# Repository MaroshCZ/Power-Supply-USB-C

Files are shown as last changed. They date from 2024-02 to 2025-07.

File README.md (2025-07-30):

# Power Supply Sink Application

To learn more about text formatting see: [Writing-on-GitHub](https://docs.github.com/en/get-started/writing-on-github/getting-started-with-writing-and-formatting-on-github/basic-writing-and-formatting-syntax)

**demo-nucleo-v0**: Basic application for Nucleo-G0B1RE + SNK1M1 based on AN5418  
**demo-nucleo-v0.1**: USB PD app for Nucleo-G0B1RE + SNK1M1 with button-triggered APDO request  
**demo-cb-v0.1**: Demo for custom board derived from demo-nucleo-v0.1 (features APDO requests)

---

# [MiniPPS](https://yourprojectpage.dev/)  
*A USB-C Programmable Power Supply with Adjustable Voltage/Current and Digital Control*

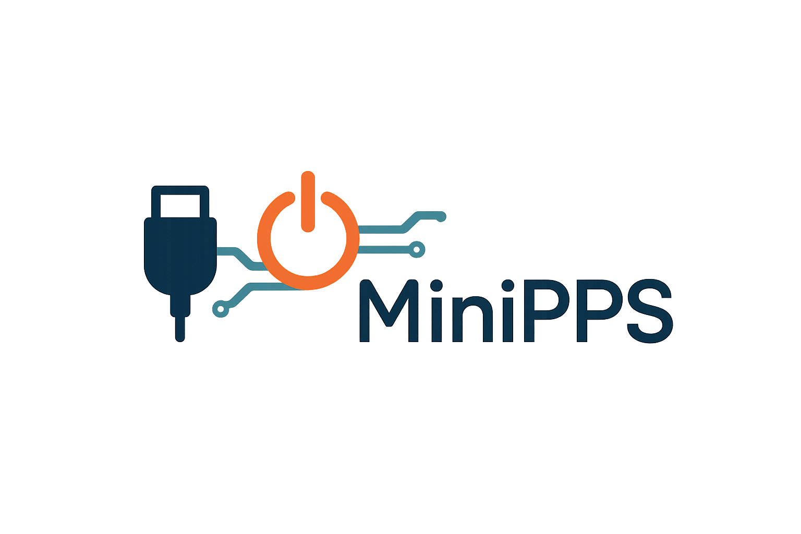
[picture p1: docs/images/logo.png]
SmartPPS banner


<div align="center">

<!--[![License](https://img.shields.io/badge/License-MIT-blue.svg)](https://opensource.org/licenses/MIT) --> 
  


</div>

---

## 📖 Table of Contents

- [Power Supply Sink Application](#power-supply-sink-application)
- [MiniPPS](#minipps)
  - [📖 Table of Contents](#-table-of-contents)
  - [🧠 About](#-about)
  - [⚙️ Features](#️-features)
    - [✅ Hardware](#-hardware)
    - [🎛️ User Interface](#️-user-interface)
    - [💻 Software](#-software)
  - [📐 Design Details](#-design-details)
    - [🔌 Schematic Overview](#-schematic-overview)
    - [🔒 Protections](#-protections)
  - [📊 Measured Performance](#-measured-performance)
  - [🛠️ Building the Project](#️-building-the-project)
  - [🚀 How to Use](#-how-to-use)
  - [🔮 Future Plans](#-future-plans)
  - [📄 License](#-license)
  - [🙏 Acknowledgments](#-acknowledgments)

---

## 🧠 About

MiniPPS is a compact, USB-C Programmable Power Supply designed to deliver **3.3V–21V**, up to **5A**, with **precision control** via buttons and an encoder. It supports USB PD 3.0 and PPS profiles and includes current sensing, SCPI command support, and optional remote control.

Ideal for embedded developers, hobbyists, and electronics students seeking a compact, user-friendly bench power supply.

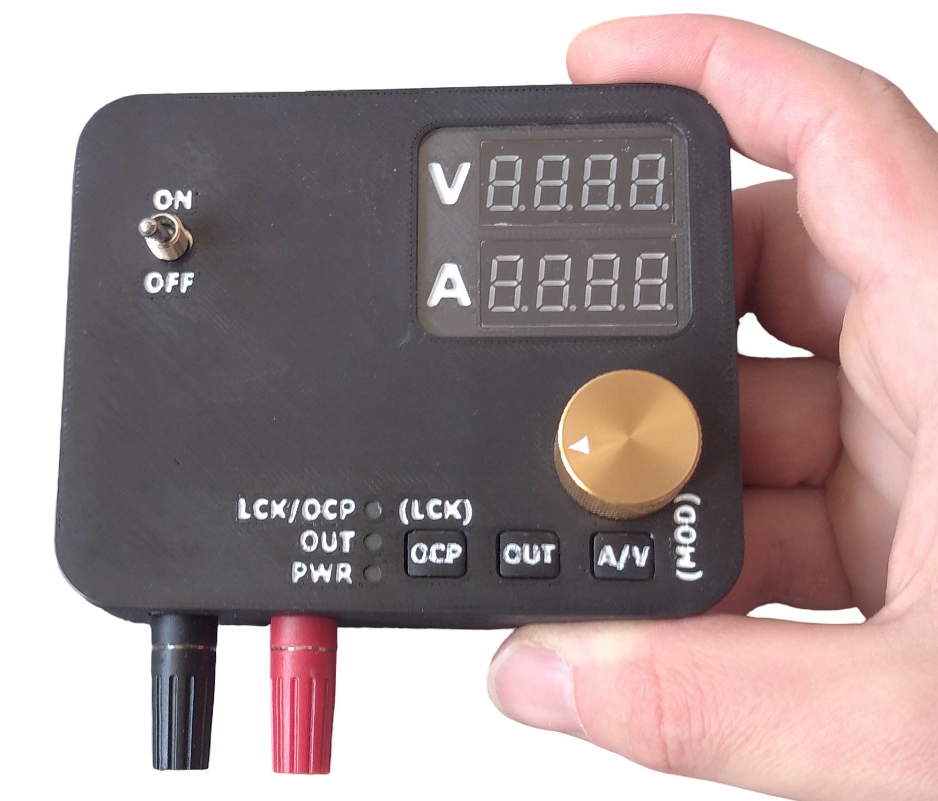
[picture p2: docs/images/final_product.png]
Device front view
<kbd></kbd>

---

## ⚙️ Features

### ✅ Hardware

- **USB-C PD Sink** supporting up to 100W (PD 3.0 + PPS)
- **TCPP01-M12** protection and **STM32G0B1RE** MCU
- **High-accuracy current sensing** (MCP6C02)
- Output switching (relay-based)
- **20mV / 1mA adjustment resolution**
- Dual 7-segment displays with MAX7219
- Optional UART interface for debugging with UCPMonitor
- Compact 4-layer PCB KiCad design

### 🎛️ User Interface

- Rotary encoder for setpoint control
- Three tactile buttons:
  - OUT on/off
  - OCP on/off + lock/unlock (long press)
  - Voltage/current + set mode (long press Fixed/PPS)
- Dual 7-segment LED display:
  - Real-time voltage/current
  - Set values display

### 💻 Software

- STM32 HAL + STM32CubeIDE (FreeRTOS optional)
- PID or step-based DAC/PWM voltage control
- Button debouncing, encoder 
- PD contract negotiation (APDO requests)
- SCPI protocol via USB for host communication with PC

---

## 📐 Design Details

### 🔌 Schematic Overview

<kbd>Block Diagram</kbd>

### 🔒 Protections

- Reverse voltage protection (Schottky diodes)
- Overcurrent protection (OCP) (MCP6C02 + AWDG/INA301 + alert) 
- Output controlled with relay
- OTP and OVP protections built into hardware (TCPP01-M12)

---

## 📊 Measured Performance

| Parameter | Value / Range |
|---|---|
| Output Voltage Range | 3.3V – 21V (depending on adapter) |
| Output Current Range | 0 – 5A |
| Max Output Power | 100W |
| Voltage Set Resolution | 20 mV |
| Current Set Resolution | 1 mA |
| Display Resolution (Voltage/Current)| 10 mV / 1 mA |
| Output Voltage Ripple (20 Hz–20 MHz)| 70–314 mVpp (depending on adapter) |
| Load Step Response Time | 0.6–21.4 ms (depending on adapter) |
| Rise/Fall Time (10–90%) | 32–428 μs |
| Voltage Accuracy (after calibration)| ±14 mV |
| Current Accuracy (after calibration)| ±4 mA |
| Protections | OVP (22V), OCP, OTP (145°C), ESD |
| Communication | USB Micro-B, custom SCPI protocol |
| Cooling | Passive (no fan) |
| Max Case Temperature @ Full Load | ~80°C (relay-based build) |
| Dimensions | 106 x 86 x 26 mm |
| Weight | 162 g |

---

## 🛠️ Building the Project

1. Download PCB Gerbers from `/hardware`
2. Order from a fab (e.g. [PCBWay](https://www.pcbway.com))
3. Assemble and solder components as per BOM
4. Flash firmware via ST-Link or Nucleo-G0B1RE
5. Connect USB-C PD source (charger or trigger)
6. Connect load and test via 4 mm banana terminals

See [Wiki – Assembly Guide](https://github.com/youruser/SmartPPS/wiki/Assembly-Guide) for details.

---

## 🚀 How to Use

1. Power the device using a USB-C PD charger or powerbank
2. Push encoder and select desired voltage or current
3. Press A/V to switch between settings
4. Press `Output ON/OFF` to enable the output
5. Monitor live output on the 7-segment display
6. Use `Lock` button to freeze or protect settings
7. Long press A/V button to switch between Fixed/PPS mode
8. Optionaly connect USB Micro-B to PC, open COM port and control via commands

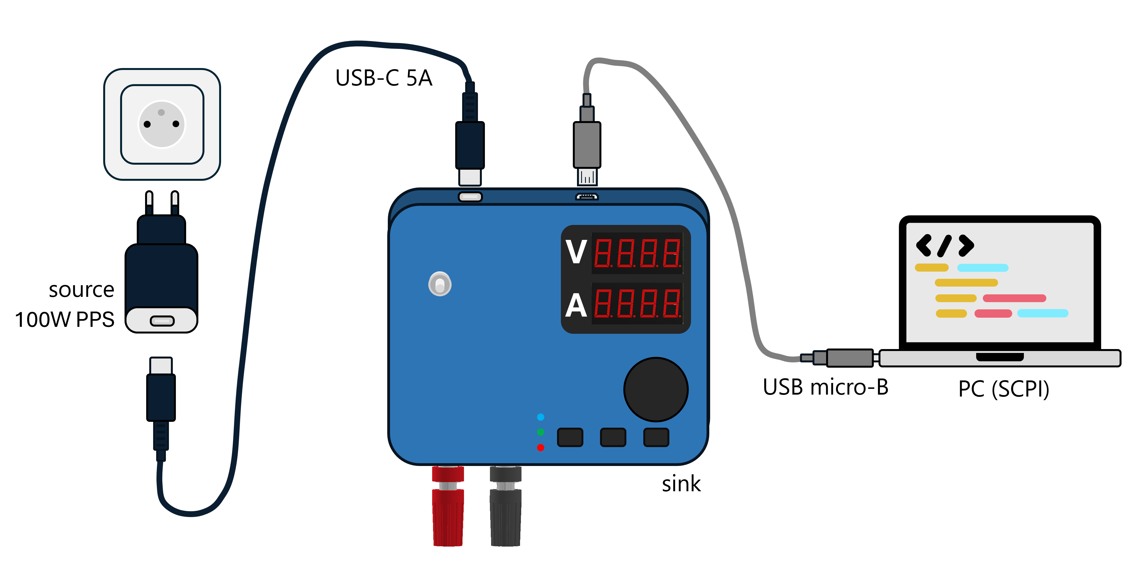
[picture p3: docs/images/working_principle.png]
Working principle
<kbd></kbd>

---

## 🔮 Future Plans

- USB PD 3.2 support (up to 48V / 5A)
- SCPI improvements and remote GUI (Qt/Python)
- Active cooling option
- Auto-ranging voltage dividers for better ADC precision
- Setting retention via emulated EEPROM

Track progress here: [GitHub Projects](https://github.com/users/youruser/projects/1)

---

## 📄 License

<!-- MIT License. See [LICENSE](LICENSE) for full details. -->

---

## 🙏 Acknowledgments

- Thanks to [STMicroelectronics](https://www.st.com/) for their excellent documentation and hardware samples
- Inspired by Tenma and RD Tech programmable PSUs
- Uses [MAX7219](https://datasheets.maximintegrated.com/en/ds/MAX7219-MAX7221.pdf), STM32G0, and KiCad
- Developed for engineers, students, and tinkerers 🚀
<!-- TODO: Developed as master thesis with collaboration and guidance from bender robotics -->

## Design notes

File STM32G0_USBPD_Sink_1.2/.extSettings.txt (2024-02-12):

[ProjectFiles]
HeaderPath=
[Others]
Define=
HALModule=
[Groups]
USBPD=USBPD\usbpd_user_services.c; USBPD\usbpd_user_services.h
Doc = C:\ST\STM32_CubeIDE\workspace1.14\UCPD\STM32G0_USBPD_Sink_1.2\Docs

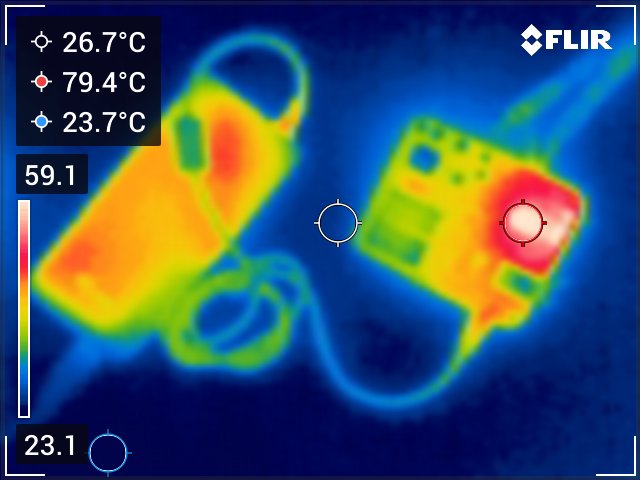
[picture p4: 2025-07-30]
docs/images/load_5A_adapter.jpg

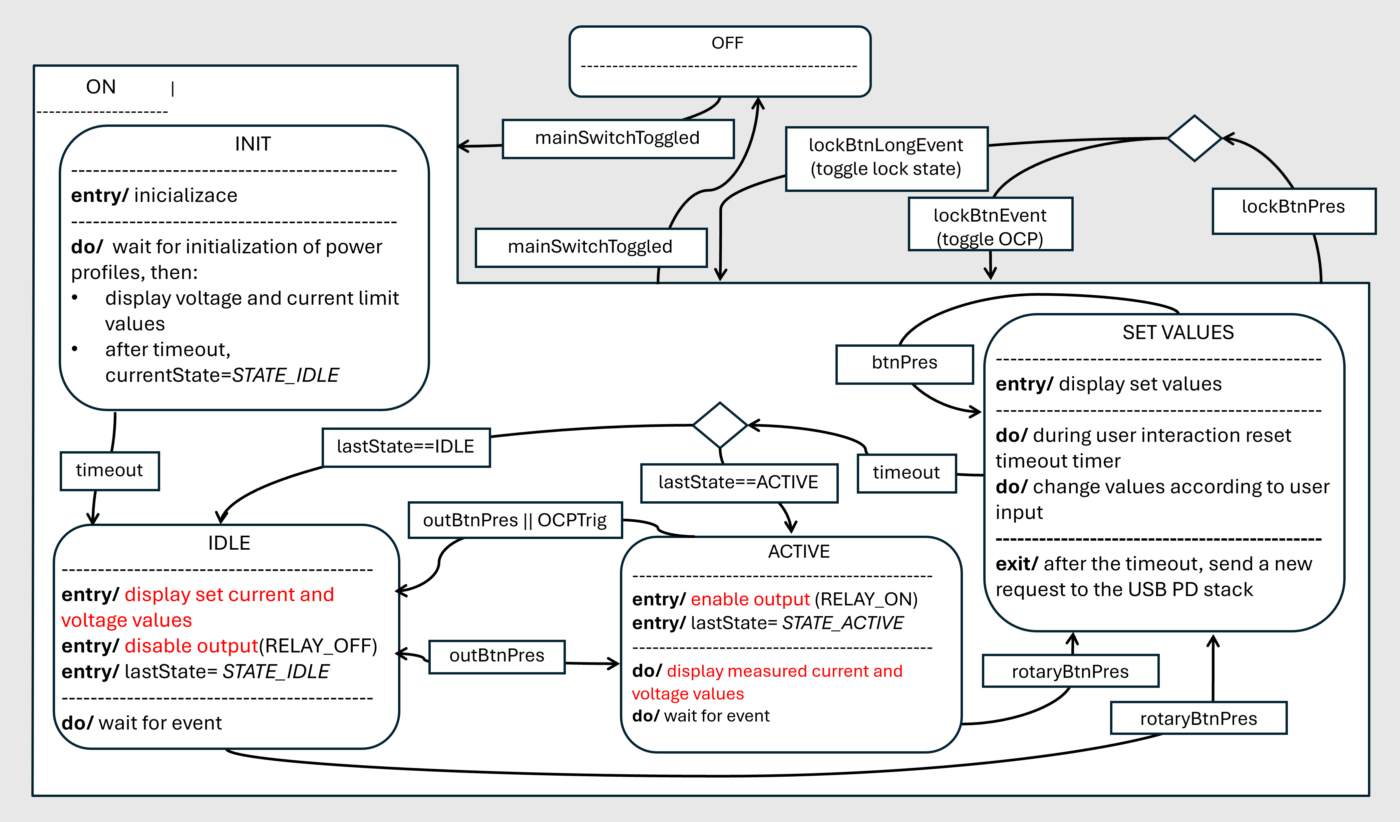
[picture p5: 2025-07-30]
docs/images/state_diagram.png

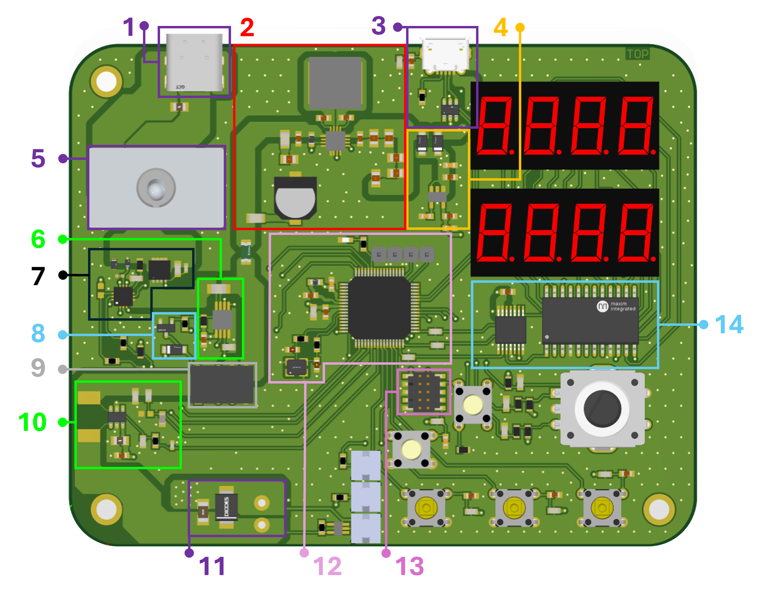
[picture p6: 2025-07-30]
docs/images/pcb_sections.png

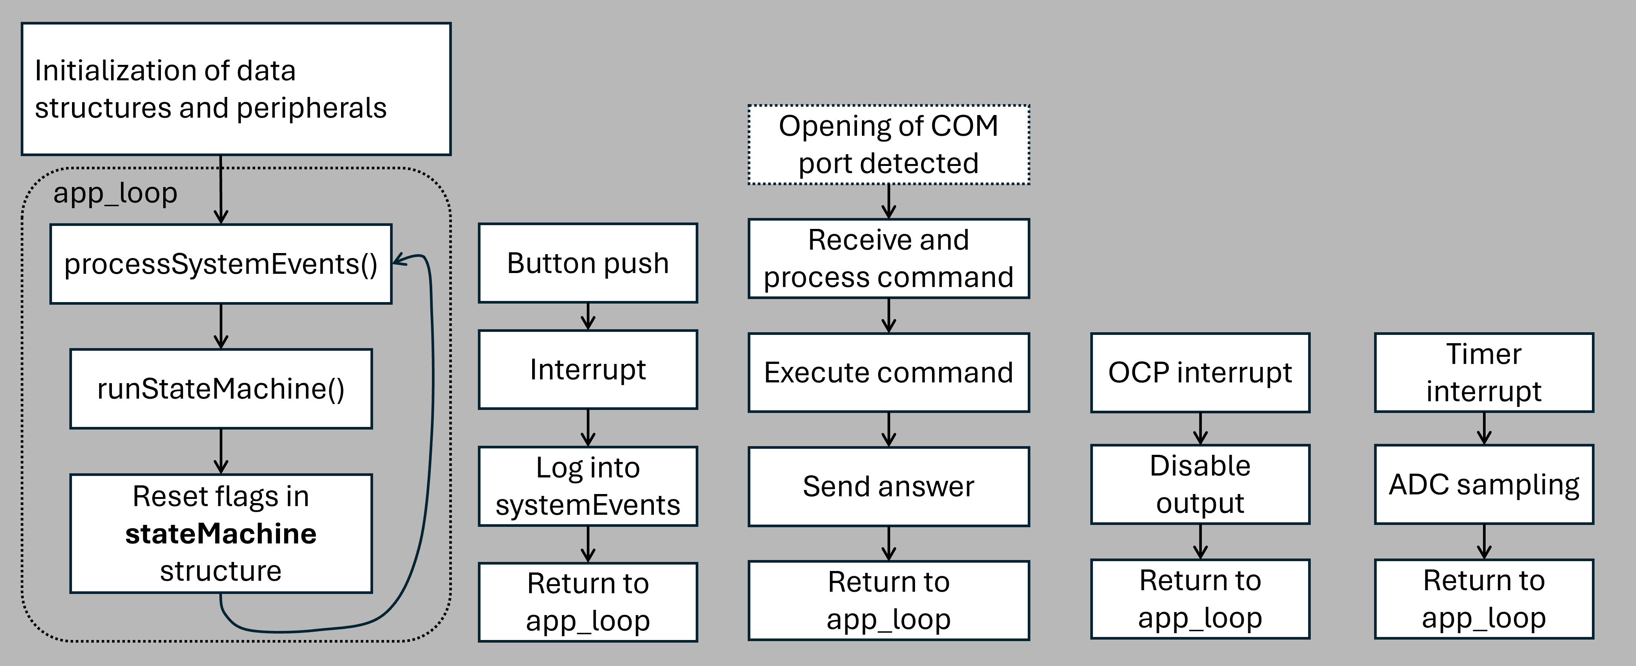
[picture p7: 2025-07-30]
docs/images/flow_diagram.png

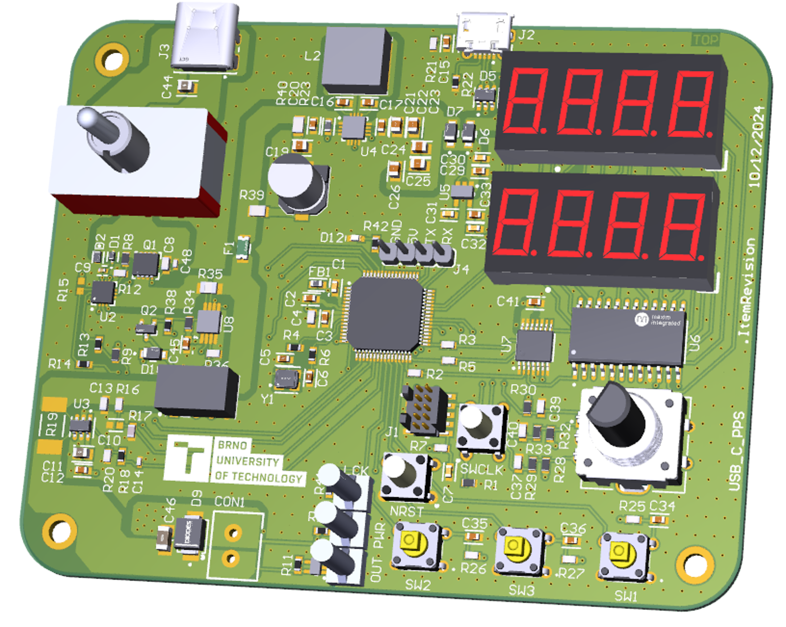
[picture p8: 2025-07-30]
docs/images/pps_dps_3d.png

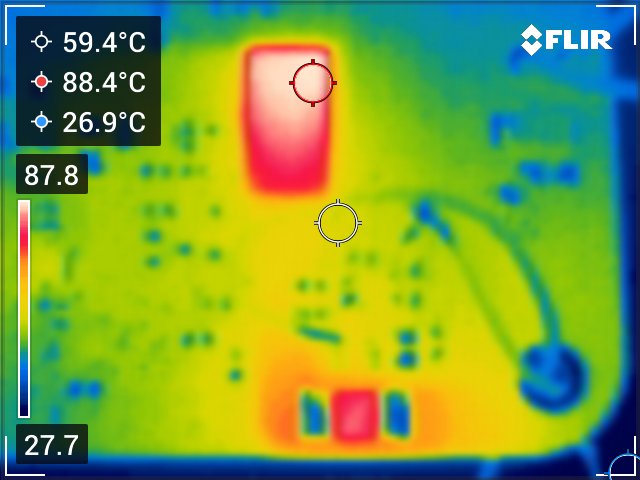
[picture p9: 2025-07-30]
docs/images/load_5A_detail.jpg

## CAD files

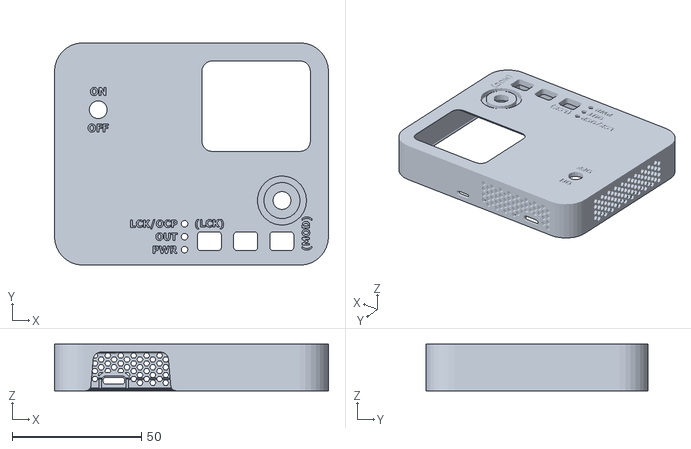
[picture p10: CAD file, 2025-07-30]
hardware/cad/Exports/top_enclosure.stl
106.0 x 86.0 x 18.0

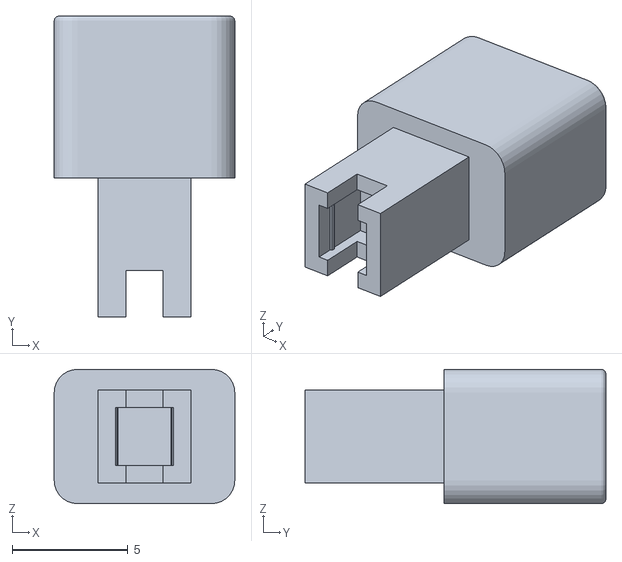
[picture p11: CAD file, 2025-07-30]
hardware/cad/Exports/button_cap.stl
7.80 x 13.0 x 5.80

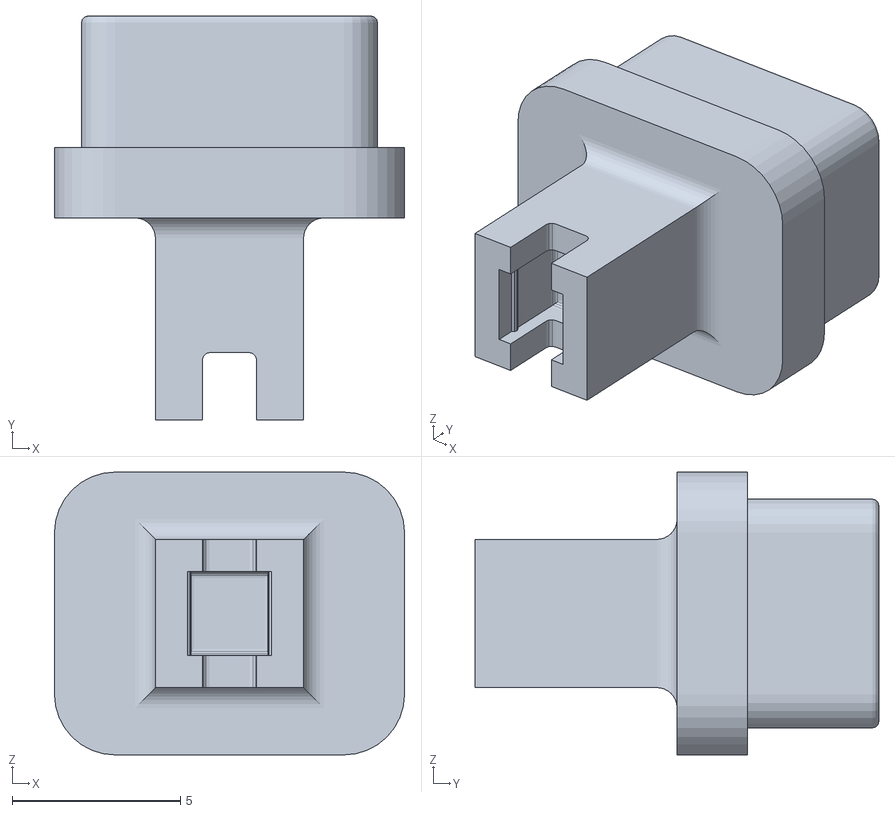
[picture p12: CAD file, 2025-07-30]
hardware/cad/Exports/button_cap_A_V.stl
10.4 x 12.0 x 8.40

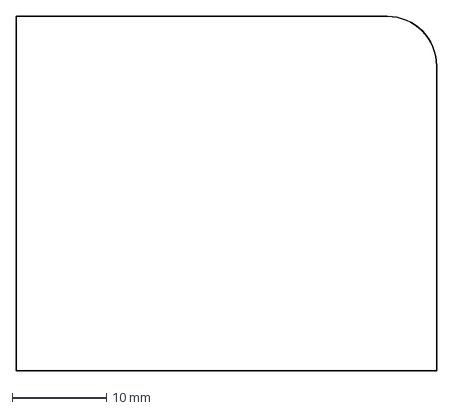
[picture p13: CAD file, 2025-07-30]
hardware/cad/Exports/plexiglass.dxf
44.5 x 37.5 mm

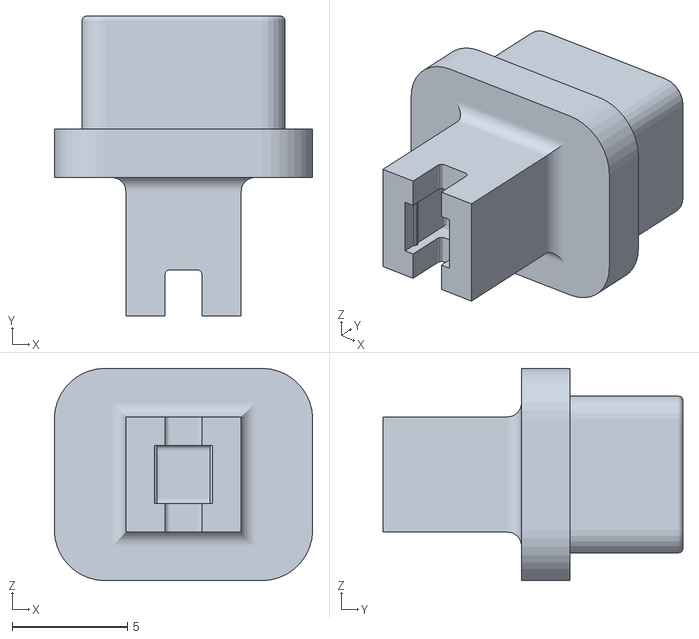
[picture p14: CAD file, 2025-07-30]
hardware/cad/Exports/button cap_v_0.4.stl
11.2 x 13.0 x 9.20

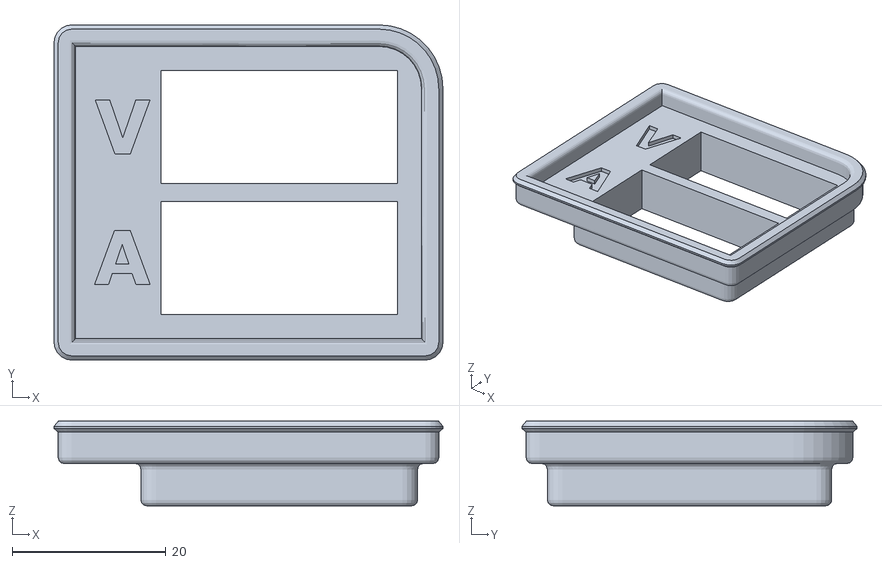
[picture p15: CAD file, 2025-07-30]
hardware/cad/Exports/display_cover_4mm.stl
50.6 x 43.6 x 11.0

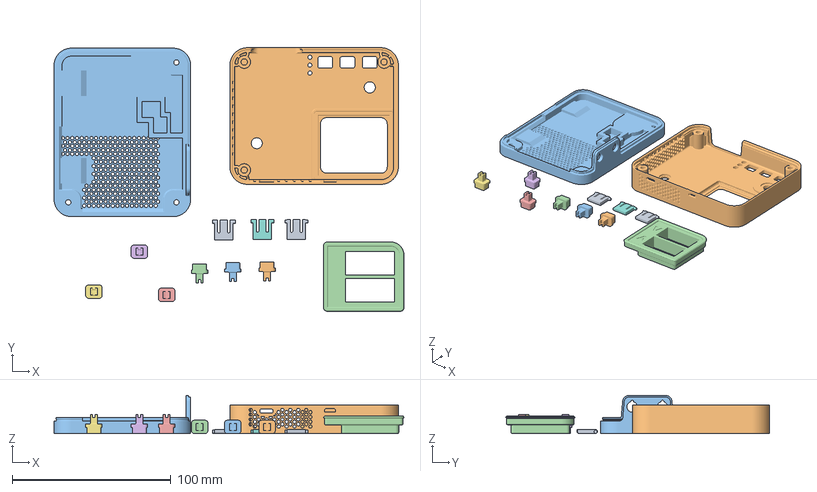
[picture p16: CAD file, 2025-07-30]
hardware/cad/Exports/bottom_enclosure_v_0.5.3mf
220.2 x 165.9 x 24.0 mm
tilt_leg_v_0.5.stl x 3
button_cap_A_V_v_0.5.stl x 2
button_cap_OUT_v_0.5.stl x 2
button_cap_OCP_v_0.5.stl x 2
top_enclosure
bottom_enclosure
display_cover_2

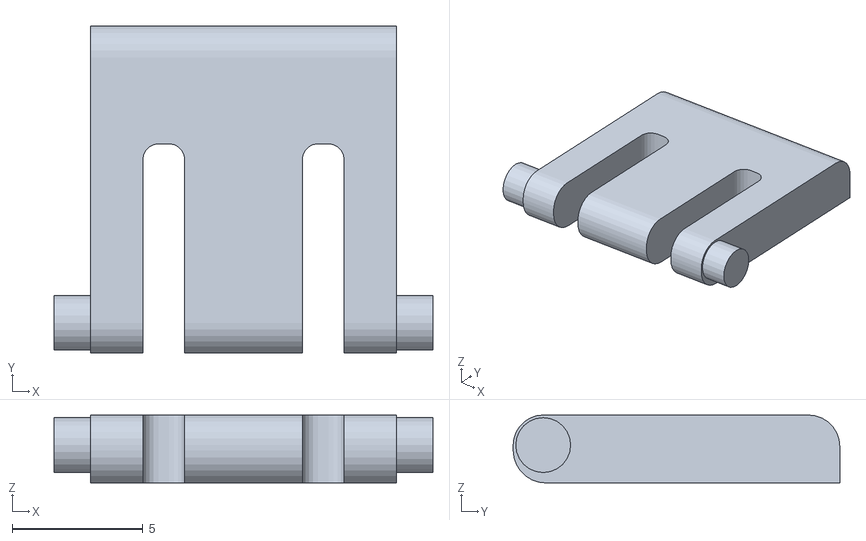
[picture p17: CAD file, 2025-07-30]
hardware/cad/Exports/tilt_leg.stl
14.5 x 12.5 x 2.60

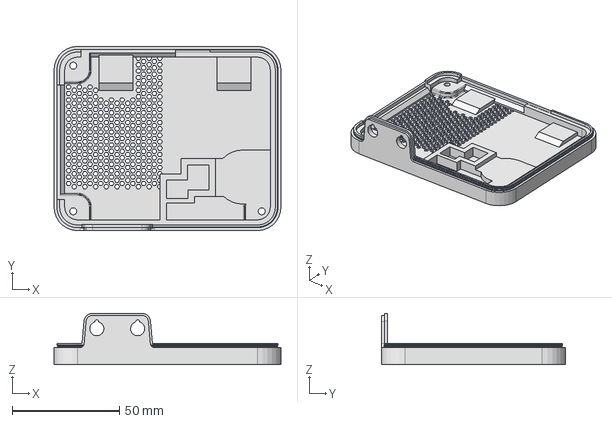
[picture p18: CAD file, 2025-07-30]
hardware/cad/Exports/bottom_enclosure.stp
106.0 x 86.0 x 24.0 mm

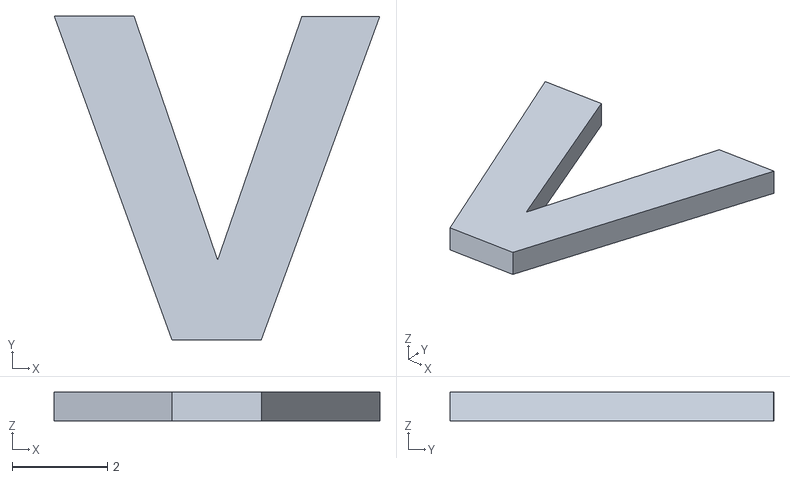
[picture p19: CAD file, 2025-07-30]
hardware/cad/Exports/V_letter.stl
6.84 x 6.81 x 0.6

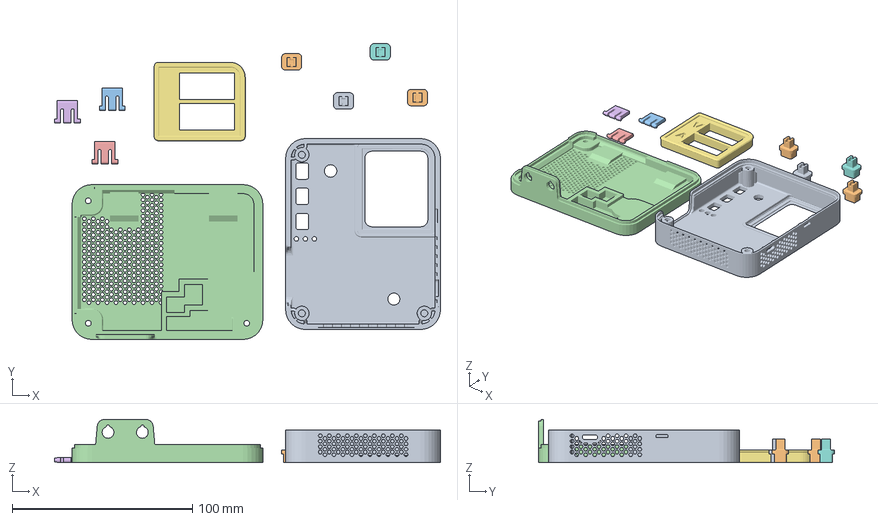
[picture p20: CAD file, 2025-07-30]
hardware/cad/Exports/print_prusa.3mf
214.3 x 164.3 x 24.0 mm
top_enclosure_v_0.4.stl
button cap_v_0.4.stl x 4
tilt_leg_v_0.4.stl x 3
bottom_enclosure_v_0.4.stl
display_cover_v_0.4.stl

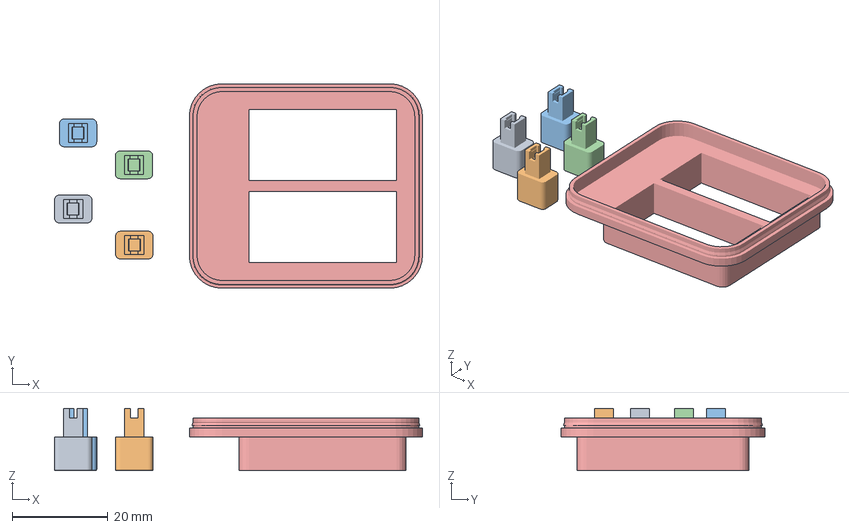
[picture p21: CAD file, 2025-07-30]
hardware/cad/Exports/display_cover_btns.3mf
76.7 x 42.6 x 13.0 mm
button_cap.stl x 4
display_cover.stl

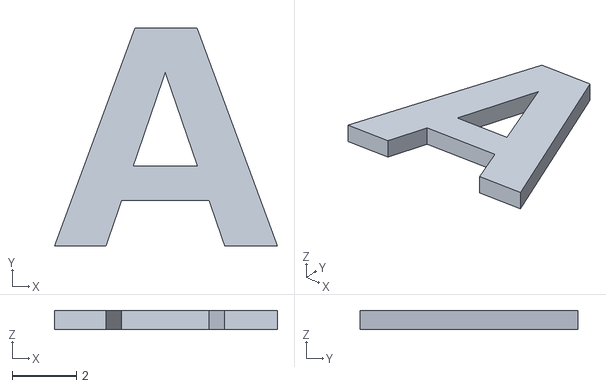
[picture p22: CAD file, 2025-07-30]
hardware/cad/Exports/A_letter.stl
6.96 x 6.80 x 0.6

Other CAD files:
hardware/cad/Exports/button_cap_OUT.stl
hardware/cad/Exports/display_cover_2mm.stp
hardware/cad/Exports/button_cap_OCP.stl
hardware/cad/A_letter.ipt
hardware/cad/ConvertedComponents/15EDGVC-3.5-02P-14_CMP-007-000009-5.ipt
hardware/cad/ConvertedComponents/1M41T1B5M1QE_1M41T1B5M1QE-1.ipt
hardware/cad/ConvertedComponents/3461AS_3461AS-1.ipt
hardware/cad/ConvertedComponents/B3F-1052_B3F-1052-1.ipt
hardware/cad/ConvertedComponents/B3F-1075_CMP-003-000047-3.ipt
hardware/cad/ConvertedComponents/C0603-IPC_B_CMP-001-00017-6.ipt
hardware/cad/ConvertedComponents/C0603-IPC_B_CMP-001-00021-6.ipt
hardware/cad/ConvertedComponents/C0603-IPC_B_CMP-001-00024-6.ipt
hardware/cad/ConvertedComponents/C0603-IPC_B_CMP-002-000092-6.ipt
hardware/cad/ConvertedComponents/CAPAE6866X80M_CMP-002-000028-3.ipt
hardware/cad/ConvertedComponents/CAPC1005X55X25NL05T10_CMP-2008-04045-1.ipt
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

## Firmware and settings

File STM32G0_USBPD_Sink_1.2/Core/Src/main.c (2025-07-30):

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
/* Includes ------------------------------------------------------------------*/
#include "main.h"
#include "cmsis_os.h"
#include "usbpd.h"
//#include "usb_device.h"

/* USER CODE BEGIN Includes */
#include <stdio.h>
#include <string.h>
#include <usbpd_trace.h>
#include <app.h>


/* USER CODE END Includes */

ADC_HandleTypeDef hadc1;
DMA_HandleTypeDef hdma_adc1;

DAC_HandleTypeDef hdac1;

SPI_HandleTypeDef hspi2;

TIM_HandleTypeDef htim3;
TIM_HandleTypeDef htim4;
TIM_HandleTypeDef htim15;

/* Definitions for defaultTask */
osThreadId_t defaultTaskHandle;
const osThreadAttr_t defaultTask_attributes = {
  .name = "defaultTask",
  .priority = (osPriority_t) osPriorityNormal,
  .stack_size = 128 * 4
};
void SystemClock_Config(void);
static void MX_GPIO_Init(void);
static void MX_DMA_Init(void);
static void MX_UCPD1_Init(void);
static void MX_ADC1_Init(void);
static void MX_LPUART1_UART_Init(void);
static void MX_TIM7_Init(void);
static void MX_SPI2_Init(void);
static void MX_TIM3_Init(void);
static void MX_DAC1_Init(void);
static void MX_TIM4_Init(void);
static void MX_TIM14_Init(void);
static void MX_TIM15_Init(void);
void StartDefaultTask(void *argument);

/**
  * @brief  The application entry point.
  * @retval int
  */
int main(void)
{
  /* MCU Configuration--------------------------------------------------------*/

  /* Reset of all peripherals, Initializes the Flash interface and the Systick. */
  HAL_Init();

  /* Configure the system clock */
  SystemClock_Config();

  /* Initialize all configured peripherals */
  MX_GPIO_Init();
  MX_DMA_Init();
  MX_UCPD1_Init();
  MX_ADC1_Init();
  MX_LPUART1_UART_Init();
  MX_TIM7_Init();
  MX_SPI2_Init();
  MX_TIM3_Init();
  MX_USB_Device_Init();
  MX_DAC1_Init();
  MX_TIM4_Init();
  MX_TIM14_Init();
  MX_TIM15_Init();
  /* USER CODE BEGIN 2 */
  app_init();
  /* USER CODE END 2 */

  /* Init scheduler */
  osKernelInitialize();
  /* USBPD initialisation ---------------------------------*/
  MX_USBPD_Init();

  /* USER CODE BEGIN RTOS_MUTEX */
  /* add mutexes, ... */
  /* USER CODE END RTOS_MUTEX */

  /* USER CODE BEGIN RTOS_SEMAPHORES */
  /* add semaphores, ... */
  /* USER CODE END RTOS_SEMAPHORES */

  /* USER CODE BEGIN RTOS_TIMERS */
  /* start timers, add new ones, ... */
  /* USER CODE END RTOS_TIMERS */

  /* USER CODE BEGIN RTOS_QUEUES */
  //app_freertos_create();
  /* USER CODE END RTOS_QUEUES */

  /* Create the thread(s) */
  /* creation of defaultTask */
  defaultTaskHandle = osThreadNew(StartDefaultTask, NULL, &defaultTask_attributes);

  /* USER CODE BEGIN RTOS_THREADS */
  /* add threads, ... */
  /* USER CODE END RTOS_THREADS */

  /* USER CODE BEGIN RTOS_EVENTS */
  /* add events, ... */
  /* USER CODE END RTOS_EVENTS */

  /* Start scheduler */
  osKernelStart();

  /* We should never get here as control is now taken by the scheduler */
  /* Infinite loop */
  /* USER CODE BEGIN WHILE */
  while (1)
  {
    /* USER CODE END WHILE */

    /* USER CODE BEGIN 3 */
  }
  /* USER CODE END 3 */
}

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
/* USER CODE BEGIN Header_StartDefaultTask */
/**
  * @brief  Function implementing the defaultTask thread.
  * @param  argument: Not used
  * @retval None
  */
/* USER CODE END Header_StartDefaultTask */
void StartDefaultTask(void *argument)
{
  /* USER CODE BEGIN 5 */
  /* Infinite loop */
  for(;;)
  {
    osDelay(1);
    app_loop();
  }
  /* USER CODE END 5 */
}

/**
  * @brief  Period elapsed callback in non blocking mode
  * @note   This function is called  when TIM6 interrupt took place, inside
  * HAL_TIM_IRQHandler(). It makes a direct call to HAL_IncTick() to increment
  * a global variable "uwTick" used as application time base.
  * @param  htim : TIM handle
  * @retval None
  */
void HAL_TIM_PeriodElapsedCallback(TIM_HandleTypeDef *htim)
{
  if (htim->Instance == TIM6) {
    HAL_IncTick();
  }
  /* USER CODE BEGIN Callback 1 */
  USBPD_DPM_TimerCounter(); //related to PD device manager
  GUI_TimerCounter(); //updating a graphical user interface (GUI) based on timer events.
  /* USER CODE END Callback 1 */
}

/**
  * @brief  This function is executed in case of error occurrence.
  * @retval None
  */
void Error_Handler(void)
{
  /* USER CODE BEGIN Error_Handler_Debug */
  /* User can add his own implementation to report the HAL error return state */
  __disable_irq();
  while (1)
  {
  }
  /* USER CODE END Error_Handler_Debug */
}

#ifdef  USE_FULL_ASSERT
/**
  * @brief  Reports the name of the source file and the source line number
  *         where the assert_param error has occurred.
  * @param  file: pointer to the source file name
  * @param  line: assert_param error line source number
  * @retval None
  */
void assert_failed(uint8_t *file, uint32_t line)
{
  /* USER CODE BEGIN 6 */
  /* User can add his own implementation to report the file name and line number,
     ex: printf("Wrong parameters value: file %s on line %d\r\n", file, line) */
  /* USER CODE END 6 */
}
#endif /* USE_FULL_ASSERT */

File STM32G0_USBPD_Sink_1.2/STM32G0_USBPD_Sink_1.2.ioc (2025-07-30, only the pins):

Mcu.UserName=STM32G0B1RETx
PA0.GPIO_Label=HighZ
PA0.Signal=GPIO_Input
PA1.GPIO_Label=FLT_IN_TCPP
PA1.Signal=GPIO_Input
PA13.Signal=SYS_SWDIO
PA14-BOOT0.Signal=SYS_SWCLK
PA2.Signal=LPUART1_TX
PA3.Signal=LPUART1_RX
PA4.GPIO_Label=OCP_DAC_LIMIT
PA4.Signal=COMP_DAC11_group
PA5.GPIO_Label=VSENSE
PA5.Signal=ADC1_IN5
PA6.GPIO_Label=OCP_ADC_I
PA6.Signal=ADC1_IN6
PA7.GPIO_Label=ISENSE
PA7.Signal=ADC1_IN7
PA8.Signal=UCPD1_CC1
PB0.GPIO_Label=DB_OUT
PB0.Signal=GPIO_Output
PB1.GPIO_Label=SW3_OFF_ON
PB1.Signal=GPXTI1
PB11.Signal=SPI2_MOSI
PB12.GPIO_Label=CS_MAX7219
PB12.Signal=GPIO_Output
PB13.Signal=SPI2_SCK
PB15.Signal=UCPD1_CC2
PB2.GPIO_Label=SW1_TOGGLE_I_V
PB2.Signal=GPXTI2
PB4.GPIO_Label=CC2_G4
PB4.Signal=GPIO_Input
PB5.GPIO_Label=LED_USER
PB5.Signal=GPIO_Output
PB6.GPIO_Label=OCP_ALERT
PB6.Signal=GPXTI6
PB7.GPIO_Label=OCP_ALERT2
PB7.Signal=GPXTI7
PB8.GPIO_Label=OCP_RESET
PB8.Signal=GPIO_Output
PC10.GPIO_Label=RELAY_ON_OFF
PC10.Signal=GPIO_Output
PC4.GPIO_Label=SW2_DEBUG_BTN
PC4.Signal=GPXTI4
PC5.GPIO_Label=LED_LOCK
PC5.Signal=GPIO_Output
PC6.GPIO_Label=ENC_TIM3_CH1
PC6.Signal=S_TIM3_CH1
PC7.GPIO_Label=ENC_TIM3_CH2
PC7.Signal=S_TIM3_CH2
PD8.GPIO_Label=ENC_TOGGLE_UNITS
PD8.Signal=GPXTI8

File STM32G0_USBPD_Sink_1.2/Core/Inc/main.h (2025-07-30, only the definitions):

#define VDDA_APPLI 3300
#define HighZ_Pin GPIO_PIN_0
#define HighZ_GPIO_Port GPIOA
#define FLT_IN_TCPP_Pin GPIO_PIN_1
#define FLT_IN_TCPP_GPIO_Port GPIOA
#define OCP_DAC_LIMIT_Pin GPIO_PIN_4
#define OCP_DAC_LIMIT_GPIO_Port GPIOA
#define VSENSE_Pin GPIO_PIN_5
#define VSENSE_GPIO_Port GPIOA
#define OCP_ADC_I_Pin GPIO_PIN_6
#define OCP_ADC_I_GPIO_Port GPIOA
#define ISENSE_Pin GPIO_PIN_7
#define ISENSE_GPIO_Port GPIOA
#define SW2_DEBUG_BTN_Pin GPIO_PIN_4
#define SW2_DEBUG_BTN_GPIO_Port GPIOC
#define SW2_DEBUG_BTN_EXTI_IRQn EXTI4_15_IRQn
#define LED_LOCK_Pin GPIO_PIN_5
#define LED_LOCK_GPIO_Port GPIOC
#define DB_OUT_Pin GPIO_PIN_0
#define DB_OUT_GPIO_Port GPIOB
#define SW3_OFF_ON_Pin GPIO_PIN_1
#define SW3_OFF_ON_GPIO_Port GPIOB
#define SW3_OFF_ON_EXTI_IRQn EXTI0_1_IRQn
#define SW1_TOGGLE_I_V_Pin GPIO_PIN_2
#define SW1_TOGGLE_I_V_GPIO_Port GPIOB
#define SW1_TOGGLE_I_V_EXTI_IRQn EXTI2_3_IRQn
#define CS_MAX7219_Pin GPIO_PIN_12
#define CS_MAX7219_GPIO_Port GPIOB
#define ENC_TIM3_CH1_Pin GPIO_PIN_6
#define ENC_TIM3_CH1_GPIO_Port GPIOC
#define ENC_TIM3_CH2_Pin GPIO_PIN_7
#define ENC_TIM3_CH2_GPIO_Port GPIOC
#define ENC_TOGGLE_UNITS_Pin GPIO_PIN_8
#define ENC_TOGGLE_UNITS_GPIO_Port GPIOD
#define ENC_TOGGLE_UNITS_EXTI_IRQn EXTI4_15_IRQn
#define CC2_G4_Pin GPIO_PIN_4
#define CC2_G4_GPIO_Port GPIOB
#define LED_USER_Pin GPIO_PIN_5
#define LED_USER_GPIO_Port GPIOB
#define OCP_ALERT_Pin GPIO_PIN_6
#define OCP_ALERT_GPIO_Port GPIOB
#define OCP_ALERT_EXTI_IRQn EXTI4_15_IRQn
#define OCP_ALERT2_Pin GPIO_PIN_7
#define OCP_ALERT2_GPIO_Port GPIOB
#define OCP_ALERT2_EXTI_IRQn EXTI4_15_IRQn
#define OCP_RESET_Pin GPIO_PIN_8
#define OCP_RESET_GPIO_Port GPIOB
#define RELAY_ON_OFF_Pin GPIO_PIN_10
#define RELAY_ON_OFF_GPIO_Port GPIOC

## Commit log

2024-02-06 Basic application of USB-C power sink. Includes also user debugg button.
    [Configuration_2024_01_24_MB1360-COM3_0.txt]
2024-02-17 Change to function HAL_TIM_PeriodElapsedCallback
    Added USBPD and GUI_TImerCOunter() so UCPD monitor GUI now shows measured voltage in chart.
2024-02-26 Implementation of Request Power profile in GUI
    Implementation of function RequestMessageRequest inside usbpd_dpm_user.c. For this purpose also funstions in usbpd_user_services.c (EvaluateMatchWithSRCPDO and BuildRDOfromSelectedPDO) were exported 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
    [Configuration_2024_02_20_Vention.txt]
2024-03-20 feat: Implement APDO power profile request with arbitrary voltage
    - previously only max voltage APDO request was possible
    - now user can request power profile with arbitrary APDO voltage in UCPD-Monitor
2024-03-21 chore: Change the folder structure
    - create new folders for docs and hardware
    - move UCPD config folder inside STM project folder
    [Configuration_2024_02_20_Vention.txt]
2024-03-26 feature: Add new project for UI testing
    - add new project for testing user interface
    - set TIM2 in encoder mode
    - add input filters to TIM2 channels
    - set encoder mode to TI1 and TI2 to detect both turning directions
    - enable auto-reload preload for TIM2
    - set SYS timebase source to TIM6
2024-03-26 feat: Add user application folder, header and source file
    [STM32G0_encoder Debug.cfg]
2024-03-26 feat: Add encoder reading
    - add encoderVal variable to store the encoder reading
    - get encoderVal reading from TIM2 counter register
2024-03-26 feat: Add encoder button press feature
    - create encoderPress variable
    - add logic for button press
    - clear EXTI interrupt flag at the end of button_isr function
    - link app_encoder.h and add button_isr to src/stm32g0xx_it.c
2024-03-26 feat: Add encoder button debouncing
    - set TIM7 debounce period to about 100ms
    - enable TIM7 IT update
    - mask interrupts on EXTI line 3 and count up to 100ms with TIM7 on each button_isr run
    - umask interrupts on EXTI line 3 and clear TIM7 update flag in timer interrupt routine
2024-04-07 fix: Change encoderBtn GPIO to falling edge detection with pull up
    [main.c]
2024-04-07 fix: Increase EncoderBtn debouncing to 150ms (TIM7)
    [main.c]
2024-04-11 feat: Add CS pin for segment display (PB0)
    - add CS pin for segment display
    - change the encoderPress logic to decrementing
2024-04-11 feat: Add voltage value based on encoder turning
    - detect the direction of encoder turning
    - define values to be added based on digit (1, 0.1,...)
    - if voltageTemp wihin limit save it to voltage variable
2024-04-11 feat: Add detection of number of integer digits and print value on display
    - add logic for detecting number of integer digits and save it to num_digits
2024-04-21 fix: Change float voltage to int
    - solve problem with float display
    - change adding variable val to integers (1,10,..)
    - change encoderPress range to 0-3
    - add for loop for printing starting zeroes
2024-04-21 feat: Add leading zero and decimal point to max7219_PrintItos
    - add third function argument for decimal point place
    - add num_digits which gets number of significant digits
    - add for loop for printing leading zeros
    - add decimal point printing using max7219_PrintDigit
2024-04-29 feat: Add TIM2 for rotary encoder
    - add TIM2 in encoder mode
    - set channel filters to 12
    - change SYS timer to TIM6 (SysTick not reccomended due to FreeRTOS)
    - enable auto-reload preload
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2024-04-29 feat: Add SPI1 and CS pin for segment display
    - add SPI1 to PA5 and PA7
    - add CS gpio output to PB0
    - set prescaler to 8 (->bit rate < 10MBits/s)
2024-04-30 feat: Add encoder button functionality
    - add encoder button to PC3
    - add TIM7 for debouncing the button (prescaler 63999 and CNT 200)
    - add button_isr() which handles masking and TIM7 nullification and start
    - add button_timer_isr() which handles TIM7 update event interrupt
2024-04-30 feat: Add encoder_turn_isr() for handling encoder turning
    - start TIM2 in IT mode in main.c init
    - read TIM2 CNT value in encoder_turn_isr() call (located in app.c)
    - attach encoder_turn_isr() to TIM2 interrupt routine
2024-04-30 feat: Add logic to encoder_turn_isr() for manipulating voltage value
    - get the direction of encoder turning
    - if required temp voltage value within limits save it to origin voltage value
    - add switch structure in button_isr, change val variable based on encoderPress value
2024-04-30 feat: Add voltage value printing to display in encoder_turn_isr()
    - get the number of digits in voltage var
    - print voltage value with max7219_PrintItos
    - extend the max7219_PrintItos() fcn by adding another argument to specify the decimal point location
2024-05-01 fix: Resolve no contract after plugging in USB-C
    - move CS_MAX7219 to PC7 pin (from PB0)
    - mark PB0 and PB4 as CC1_G4 and CC2_G4 pins to secure their position (they are needed for proper connection)
    [STM32G0_USBPD_Sink_1.2.ioc, main.c, main.h]
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2024-05-05 fix: Solve incorrectly displayed digit by BlinkDigit() after encoderTurn interrupt
    - make BlinkDigit() function change and parse voltage value as an address
    [app.c, max7219.c]
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2024-06-25 feat: Add logic and displaying of user current adjustments
    - differentiate between adjustment states (ADJUSTMENT_CURRENT/ADJUSTMENT_VOLTAGE)
    - set cur_vol_button_isr() on PC1 to toggle the adjustment state
    - make two different cases in encoder_turn_isr() to handle each state
    - fix max7219_BlinkDigit() fcn from max7219.c in order to handle usage of both 7 segment displays
    [STM32G0_USBPD_Sink_1.2.ioc, app.c, app.h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]
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2025-02-18 fix: Solve hardfault error by increasing size of _str for newly added debug traces
    [app.c]
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2025-02-22 fix: Correct calculation of VBUSGetCurrent - update BSP_USBPD_PWR_VBUSGetCurrent() to custom board - update description of GetCurrent and GetVoltage fcn - adjust DEBUG_BTN callback (sprintf->snprintf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
    [STM32G0_USBPD_Sink_1.2.ioc, main.c, main.h]
2025-02-24 feat: Add OCP_DAC_LIMIT and OCP_ADC_I pins - migrate OCP_DAC_LIMIT to correct DAC external pin (PA0->PA4) - move OCP_ADC_I to correct ADC pin (PC3->PA6)
    [STM32G0_USBPD_Sink_1.2.ioc, main.c, main.h]
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2025-02-24 feat: Add control of OCP current limit with DAC - calculate DAC output voltage based on user selected OCP current - recalculate DAC voltage to 2^12 resolution - fix some warnings (variable types in D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
    [app.c, app.h]
2025-02-26 fix: Move DAC calculation from app_loop() to encoder_turn_isr() - move DAC calc to reduce computational resources - correct encoder_turn_isr() ADJUSTMENT_CURRENT_OCP case spelling (current->currentOC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
    [STM32G0_USBPD_Sink_1.2.ioc, app.c, main.c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]
2025-03-01 feat: Add funcionality of toggling FixedPDOs when no APDO present in wall adapter - adjust USER_SERV_FindSRCIndex() in usbpd_user_services.c - find nbr of Fixed and APDOs (whne no APDO find next Fixe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
2025-03-04 fix: Fix temporarily USB PD stack init - fix correct negotiation of 12V after cable attach without need for cloding relay - use brute force to write vbus=5V in fcn USB_PWR_IF_GetVBUSStatus() located 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
    [app.c, main.c]
2025-03-05 fix: Correct logic of segment displays - set CNT register of TIM3 (ENC) to non zero value to avoid shift between 0 and max value - correct direction of turning and adding values in encoder_turn_isr()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
    [STM32G0_USBPD_Sink_1.2.ioc, app.c, app.h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]
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2025-03-12 fix: Change OCP mode to latch and adjust encoder direction - change OCP mode to latch by setting OCP_RESET_GPIO high - add logic to app_loop which resets the OCP alert by briefly pulling the OCP_RESE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
    [STM32G0_USBPD_Sink_1.2.ioc, app.c, main.c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]
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2025-03-15 feat: Define rtos queue and task to handle segment displays - define task and queue in app_freertos.c - call it via app_freertos_create() in main.c - this rtos is blocking for now (needs to be fixed)
    [STM32G0_USBPD_Sink_1.2.ioc, app.h, main.c]
2025-03-15 fix: Adjust sourcecapa_limits() fcn and specify its call - refactor sourcecapa_limits() fcn - define SNK_data() struct to hold app data - wrap this fcn into USER_SERV_ExtractSRCCapa() in user_service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
    [app.c, app.h]
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2025-03-17 fix: Update voltage divider resistor values - change voltage divider to 200k and 36k from (200k, 40k2) - use 0.1% precision resistors - new range can measure even 22V
    [STM32G0_USBPD_Sink_1.2.ioc, app.h, main.c]
2025-03-17 fix: Correct ADC channel assignment for AWDG - change channel 3 to 7 (actual ISENSE) - reduce timeout for writing DB_OUT pín in init
    [STM32G0_USBPD_Sink_1.2.ioc, app.c]
2025-03-17 fix: Adjust Update_AWD_Tresholds() fcn - specify just AWDG number, low and high treshold - erase ADC start and stop - migrate from AWDG3->AWDG2
    [STM32G0_USBPD_Sink_1.2.ioc, app.c, main.c]
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2025-03-18 feat: Add logic to detect short and long presses of SW1 - configure SW1 pit to trigger interrupt on both falling and raising edge - use HAL_GPIO_EXTI_Rising_Callback (and falling) to procces logic - 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
    [STM32G0_USBPD_Sink_1.2.ioc, app.c, app.h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]
2025-03-23 fix: Correct handling of encoderPress and Turn in SetValuesState - ensure that if current state is SetValues user action (encPress/Turn) resets timeout - process encoderTurn (inside SetValuesState) -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
    [app.c, app.h, main.c]
2025-03-23 fix: Repair periodic meas read in ACTIVE state and proccesing of voltageCurrentBtn in SetValuesState
    [main.c]
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2025-03-24 Revert "feat: Add new hardware timer for counting state timeouts"
    This reverts commit daa86dfe0aeb837fe6868f8680b4df3f8b80e7e6.
    fix: Revert to previous commit
    [STM32G0_USBPD_Sink_1.2.ioc, app.c, main.c]
2025-03-27 fix: Fix hard fault error by commenting UpdateVoltage/Current fcns in SetValuesState
    [app.c, app.h]
2025-03-27 fix: Solve implicit declaration warnings
    [app.c, app.h]
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2025-03-28 fix: Solve repeated HardFault error by erasing USBPD_TRACE_Add() from updateVoltage and Current functions - call USBPD_TRACE_Add() outside UpdateVoltage and current - add periodicCheckFlag and stateT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
    [app.c, app.h]
2025-03-29 fix: Correct handling of OCP and AWDG settings
    [app.c, app.h]
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2025-03-29 feat: Add processUSBCommand - add processUSBCommand() that is called in CDC_Receive_FS() located in usbpd_cdc_if.c - create usbBuffer getter function to avoid using extern
    [app.c, app.h]
2025-03-29 fix: Improve command recognition by using strcmp instead of strncmp
    [app.c]
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2025-03-30 fix: Fix wrong direction at first encoder turn by copying TIM3 CNT value at init to sm struct
    [app.c, app.h]
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2025-03-31 feat: Add encoder.turnEvent handling in MODE_FIXED - MODE_FIXED can be entered via long press of SW1 - in this mode encoder turn results in different FIXED voltage profile - limits of current are upd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
    [app.c, app.h]
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2025-03-31 feat: Add correct handling of updateVoltage in MODE_APDO - at beginning extract max bounds of all APDOs - check if newly selected is within bounds, if yes assign to voltageSet - lastly go backwards t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
    [app.c]
2025-04-01 fix: Add if condition to updateVoltage FIXED mode - add additional else if that is called when index >= number of profiles - this is needed for source with only fixed profiles
    [app.c]
2025-04-01 fix: Add maxvoltage and max current extraction that is copied into dhandle range to FIXED case in source_capa_limits()
    [app.c]
2025-05-21 feat: Create demo of correctOutputVoltage() fcn for periodic correction based on load - tweak PDO request in timeout of handleSetValuesState() - make a correction of handleComporststatus(), so it doe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
    [app.c, app.h, main.c]
2025-05-21 feat: Add function correctCurrentMeas() for measurement error compensation
    [app.c, app.h]
2025-05-21 fix: Update compensateVoltage() and pdo request logic in setValuesState() - add new correction formula to compensateVOltage() - for request, if MODE_FIXED use selectedProfile field from SNKData, else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
    [app.c, app.h]
2025-05-21 feat: Add output voltage measurement correction with function correctMeasVoltage() - in first step apply correction based on load current - in second step apply correction based on voltage level
    [app.c, app.h]
2025-05-23 feat: Finish correction of measured voltage and regulation of output voltage - fix and finish function correctVoltageMeas() - finish correctOutputVoltage() - change LOCK LED behaviour - erase erased 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
    [app.c, app.h]
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2025-05-23 chore: Erase legacy encoder demo project
    [STM32G0_encoder Debug.cfg]
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2025-07-25 chore: Add cad folder and 3D data
    [15EDGVC-3.5-02P-14_CMP-007-000009-5.0001.ipt, 15EDGVC-3.5-02P-14_CMP-007-000009-5.ipt, 1M41T1B5M1QE_1M41T1B5M1QE-1.0001.ipt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]

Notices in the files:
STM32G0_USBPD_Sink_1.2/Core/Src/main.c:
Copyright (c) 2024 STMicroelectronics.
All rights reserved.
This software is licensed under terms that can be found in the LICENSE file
